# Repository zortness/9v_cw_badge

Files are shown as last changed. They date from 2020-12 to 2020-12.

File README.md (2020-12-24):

# 9V QRP BADGE Transciever

Based on the schematic and work of Jeff Anderson, [K6JCA](https://www.qrz.com/db/k6jca)
and [this blog post](http://k6jca.blogspot.com/2009/08/9v-qrp-transceiver.html).

Variant of the smaller [9V battery-sized version](https://github.com/zortness/9v_cw_tx).

## About

This is a very simple, direct conversion CW transciever that will operate on the 40m 
amateur radio band. It requires an external speaker or headphones, an external antenna,
and a power source between 5 and 12 volts.

**This is still a work in progress.**

Changes from the micro version:
* larger credit card or badge size (55mm X 85mm)
* includes 7-element low pass filter (LPF) based on the QCX design with T-37-2 toroids
* includes ATTiny402 to control keying output, and reading buttons
* includes buttons for DIT and DAH 
* includes 9x2 header pinout for exposing and adding functionality (or fancy covering)

## Schematics

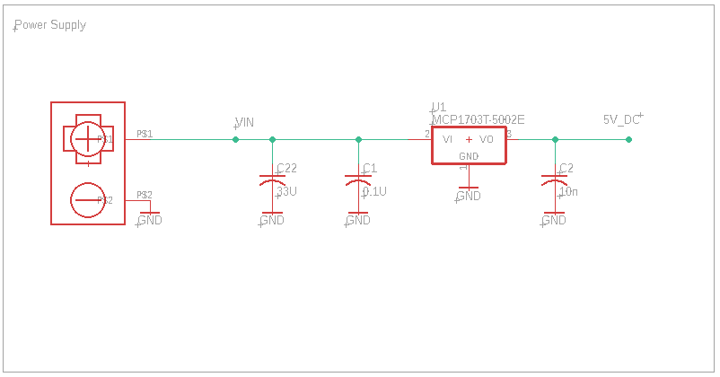
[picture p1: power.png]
Power schematic


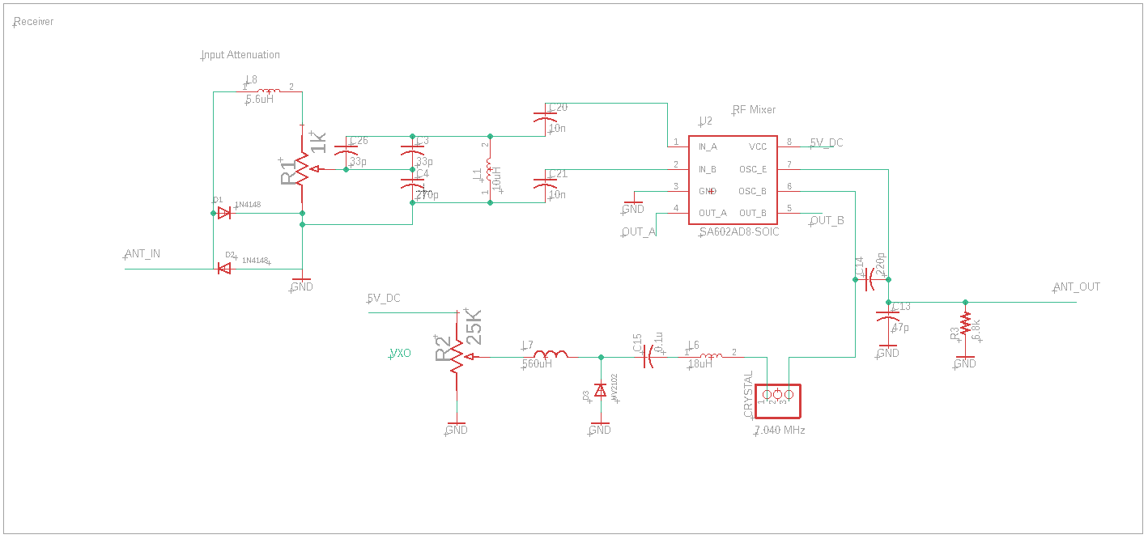
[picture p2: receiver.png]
Receiver schematic


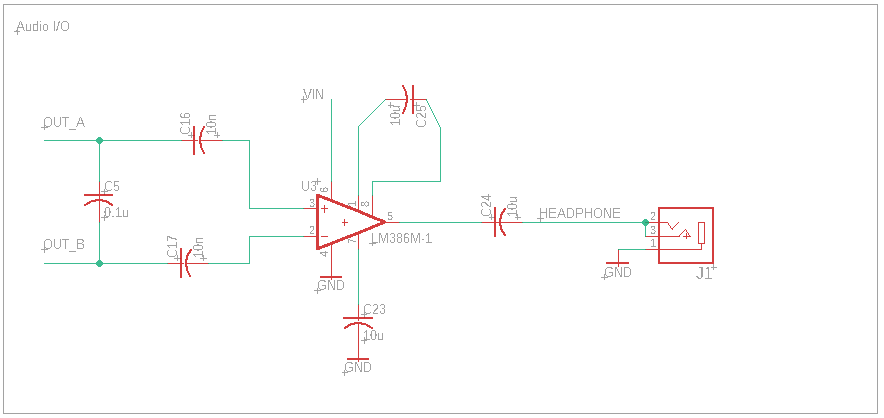
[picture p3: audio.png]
Audio schematic


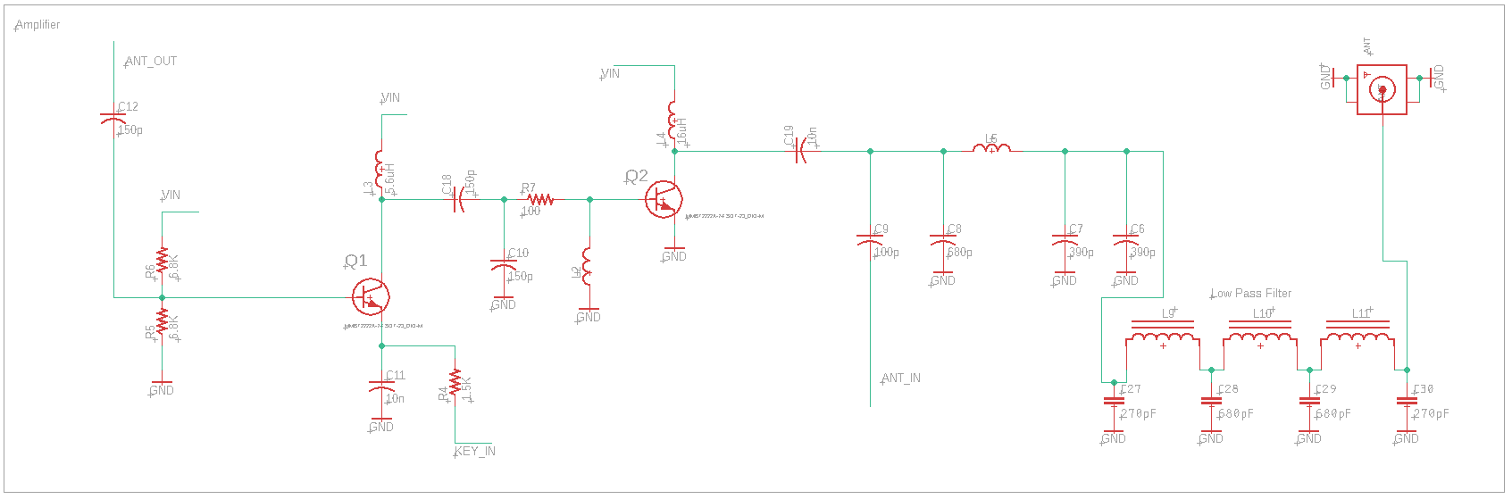
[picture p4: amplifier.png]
Amplifier schematic


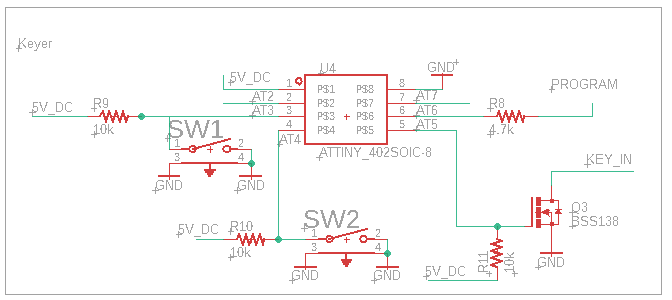
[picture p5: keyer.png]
Keyer schematic


## Board Layouts

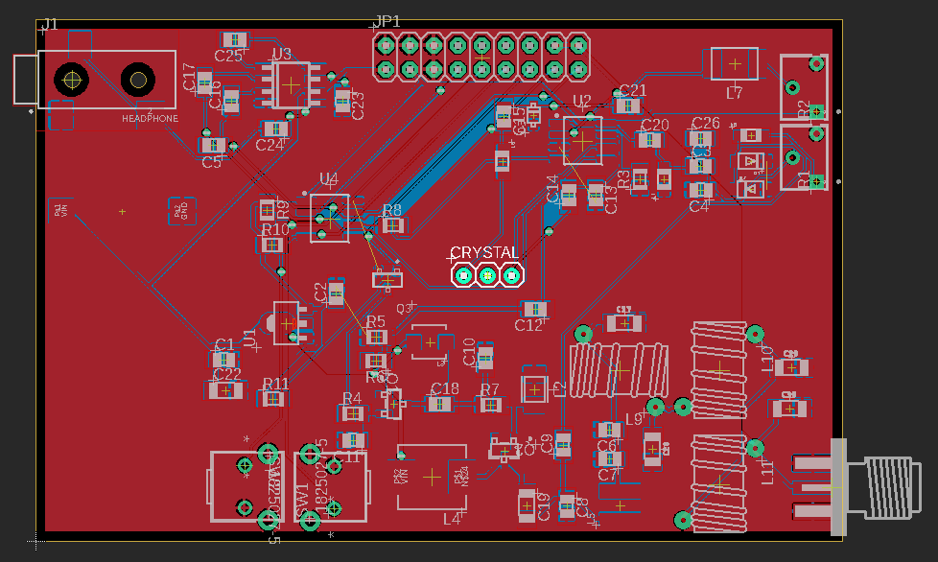
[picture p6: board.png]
Board layout


## SMD BOM

** WIP **

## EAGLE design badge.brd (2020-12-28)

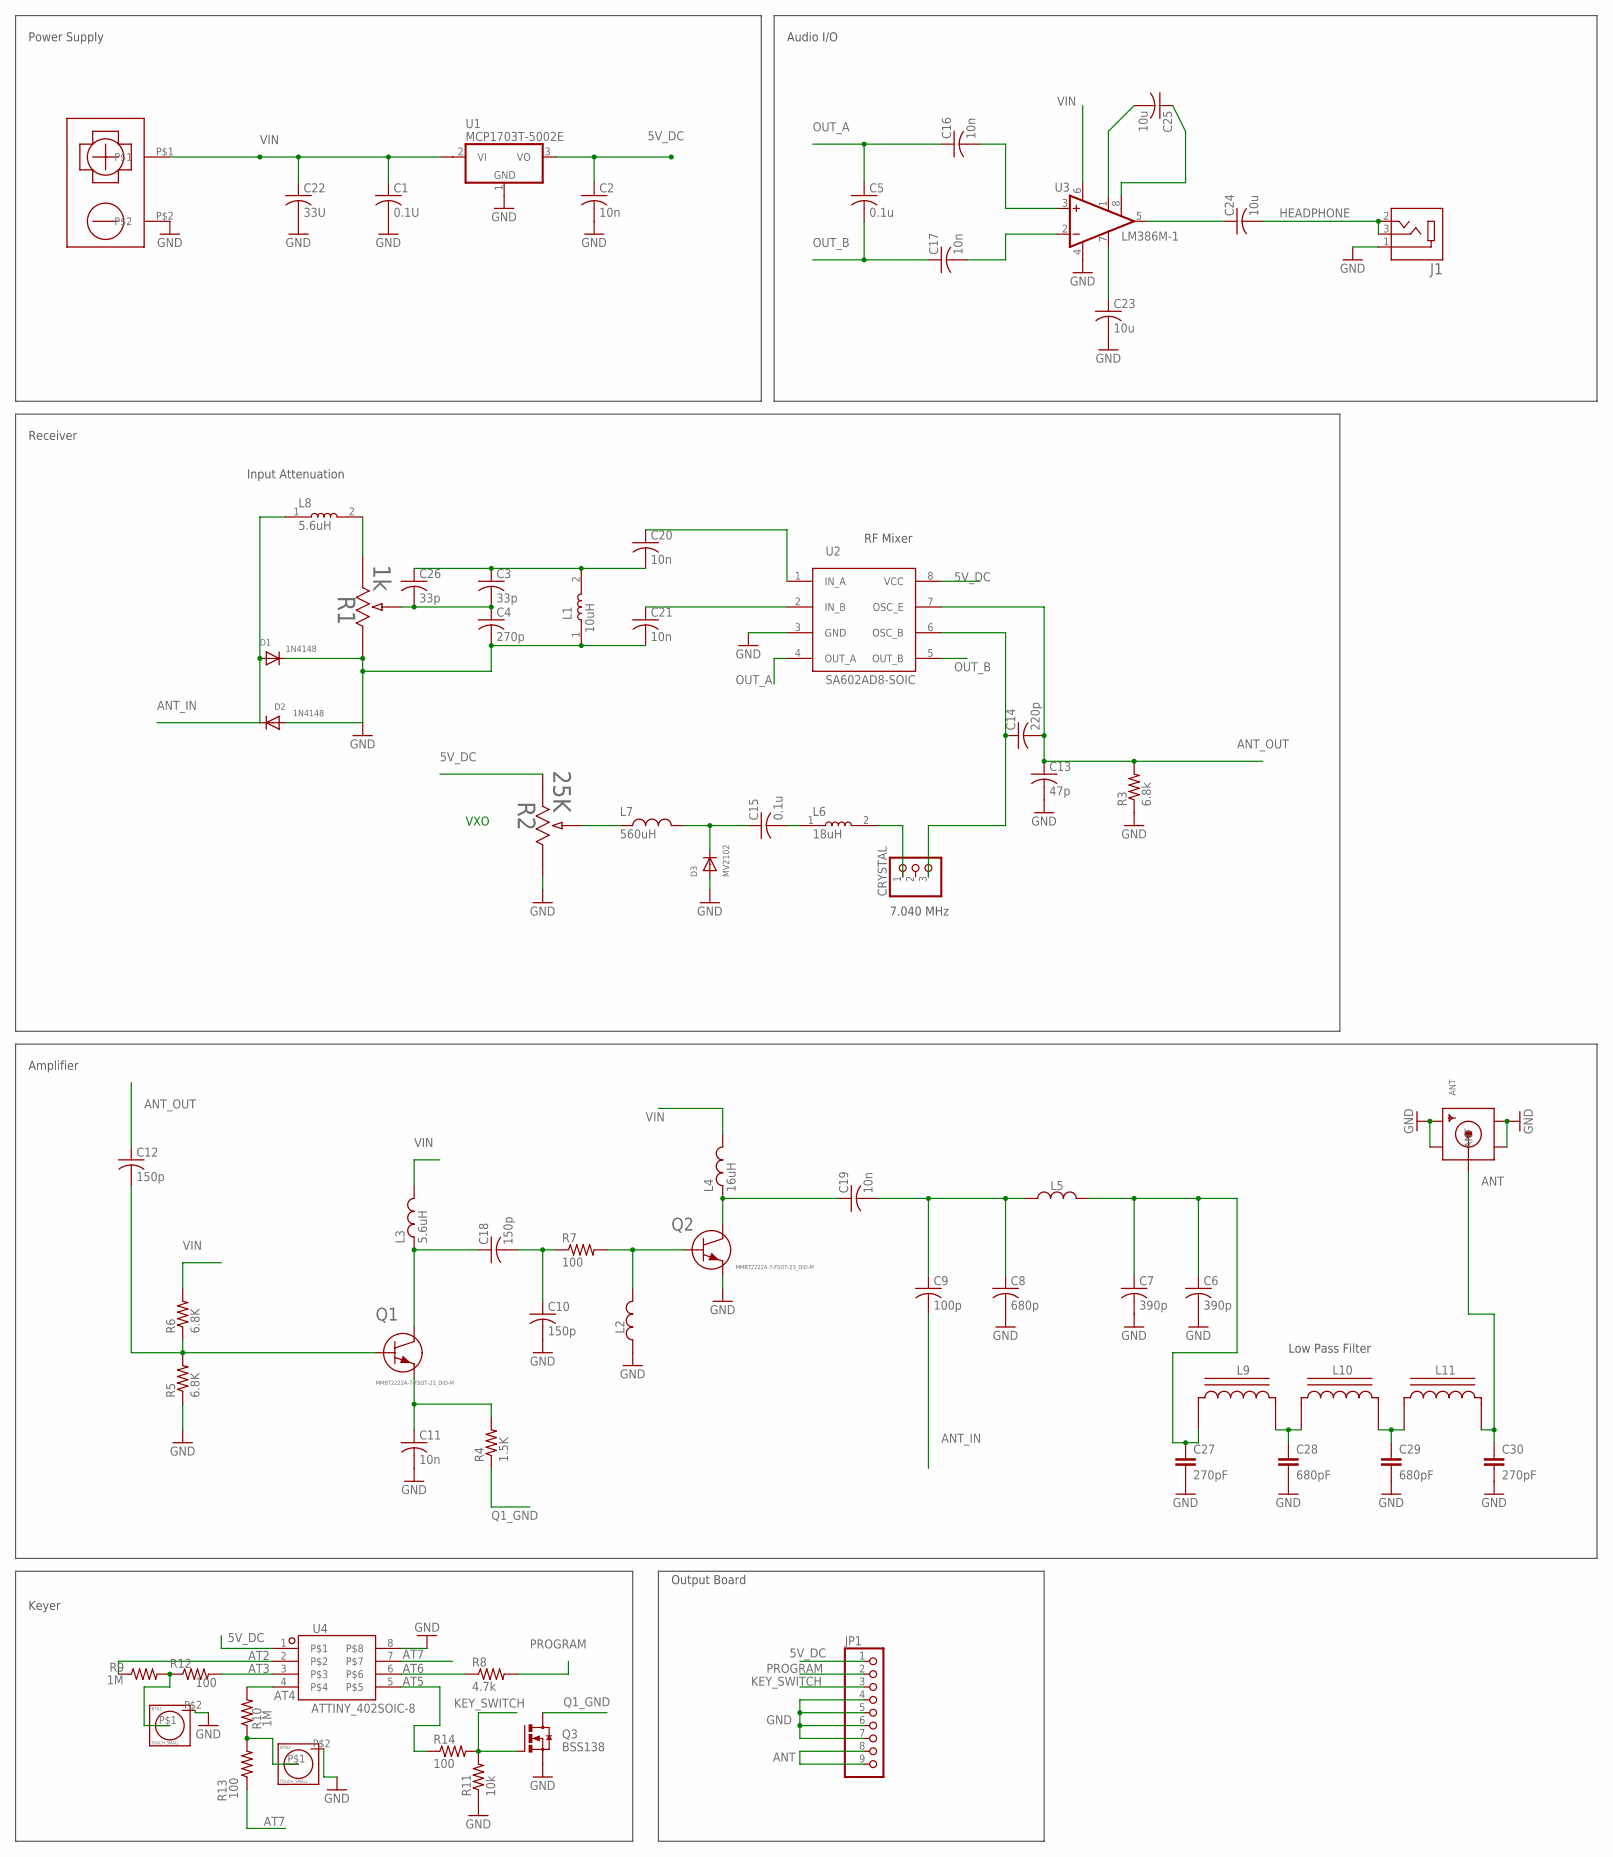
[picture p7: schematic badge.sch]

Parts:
ANT: SMACONNECTOR_EDGE; SMA_EDGELAUNCH
BTN1, BTN2: TOUCH_SMALL
C1: 0.1U; C0805
C2, C11, C16, C17, C20, C21: 10n; C0805
C3, C26: 33p; C0805
C4: 270p; C0805
C5, C15: 0.1u; C0805
C6, C7: 390p; C0805
C8: 680p; C0805
C9: 100p; C0805
C10, C12, C18: 150p; C0805
C13: 47p; C0805
C14: 220p; C0805
C19: 10n; C1206
C22: 33U; C1206
C23, C24, C25: 10u; C0805
C27, C30: 270pF; 1206
C28, C29: 680pF; 1206
CRYSTAL: PINHD-1X3; 1X03
D1, D2: 1N4148; SOD-123FL
D3: MV2102; SOD-323F
J1: SJ-3523-SMT-TR; CUI_SJ-3523-SMT-TR
JP1: PINHD-1X9; 1X09-BIG
L1: 10uH; INDC2012X87N
L2: L_CHIP-1008(2520-METRIC); INDC2520X120N
L3: 5.6uH; SRP3012C
L4: 16uH; ASPI-0630LR
L5: 1.2uH; SRN4018TA
L6: 18uH; INDC2012X87N
L7: 560uH; INDM4532X32_W
L8: 5.6uH; INDC2012X87N
L9, L11: 1.38uH; T37_INDUCTOR
L10: 1.67uH; T37_INDUCTOR
Q1, Q2: MMBT2222A-7-FSOT-23_DIO-M; SOT-23_DIO-M
Q3: BSS138; SOT23-3
R1: 1k; POT_3362W
R2: 25K; POT_3362W
R3: 6.8k; M0805
R4: 1.5K; M0805
R5, R6: 6.8K; M0805
R7, R12, R13, R14: 100; M0805
R8: 4.7k; M0805
R9, R10: 1M; M0805
R11: 10k; M0805
U1: MCP1703T-5002E; SOT89
U2: SA602AD8-SOIC; SOIC127P599X175-8N
U3: LM386M-1; SO08
U4: ATTINY_402SOIC-8; SOIC127P599X175-8N
U$1: 9V_9689V_968_SMD; 9V_968_PAD

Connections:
5V_DC: C2.1, JP1.1, R2.1, U1.3 (VO), U2.8 (VCC), U4.1
ANT: ANT.P (ANT), C30.1, JP1.8, JP1.9, L11.CA
ANT_IN: C9.2, D1.A, D2.C, L8.1
ANT_OUT: C12.1, C13.1, C14.2, R3.2, U2.7 (OSC_E)
AT2: R9.1, U4.2
AT3: R12.2, U4.3
AT4: R10.2, U4.4
AT5: R14.1, U4.5
AT6: R8.1, U4.6
AT7: R13.1, U4.7
GND: ANT.GND@1 (GND4), ANT.GND@3 (GND2), BTN1.P$2, BTN2.P$2, C1.2, C2.2, C4.2, C6.2, C7.2, C8.2, C10.2, C11.2, C13.2, C21.2, C22.2, C23.2, C27.2, C28.2, C29.2, C30.2, D1.C, D2.A, D3.A, J1.1, JP1.4, JP1.5, JP1.6, JP1.7, L1.1, L2.1, Q3.2 (S), R1.3, R2.3, R3.1, R5.1, R11.1, U1.1 (GND), U2.3 (GND), U3.4 (GND), U4.8, U$1.P$2
HEADPHONE: C24.2, J1.2, J1.3
KEY_SWITCH: JP1.3, Q3.1 (G), R11.2, R14.2
unnamed: C20.1, U2.1 (IN_A)
unnamed: C21.1, U2.2 (IN_B)
unnamed: C3.1, C20.2, C26.1, L1.2
unnamed: C3.2, C4.1, C26.2, R1.2
unnamed: L8.2, R1.1
unnamed: C14.1, CRYSTAL.3, U2.6 (OSC_B)
unnamed: C16.2, U3.3 (+IN)
unnamed: C17.2, U3.2 (-IN)
unnamed: C23.1, U3.7 (BYPASS)
unnamed: C25.1, U3.8 (GAIN)
unnamed: C25.2, U3.1 (GAIN)
unnamed: C24.1, U3.5 (OUT)
unnamed: CRYSTAL.1, L6.2
unnamed: C15.2, L6.1
unnamed: C15.1, D3.C, L7.2
unnamed: L7.1, R2.2
unnamed: C12.2, Q1.1, R5.2, R6.1
unnamed: C11.1, Q1.2 (3), R4.2
unnamed: C18.1, L3.P$1 (1), Q1.3 (2)
unnamed: C10.1, C18.2, R7.1
unnamed: L2.2, Q2.1, R7.2
unnamed: C19.1, L4.P$1 (1), Q2.3 (2)
unnamed: C8.1, C9.1, C19.2, L5.P$1 (1)
unnamed: C6.1, C7.1, C27.1, L5.P$2 (2), L9.CB
unnamed: BTN1.P$1, R9.2, R12.1
unnamed: C28.1, L9.CA, L10.CB
unnamed: C29.1, L10.CA, L11.CB
unnamed: BTN2.P$1, R10.1, R13.2
OUT_A: C5.1, C16.1, U2.4 (OUT_A)
OUT_B: C5.2, C17.1, U2.5 (OUT_B)
PROGRAM: JP1.2, R8.2
Q1_GND: Q3.3 (D), R4.1
VIN: C1.1, C22.1, L3.P$2 (2), L4.P$2 (2), R6.2, U1.2@1 (VI1), U3.6 (VS), U$1.P$1

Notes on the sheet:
Power Supply
Audio I/O
Input Attenuation
RF Mixer
VXO
7.040 MHz
Receiver
Amplifier
Low Pass Filter
Keyer
Output Board

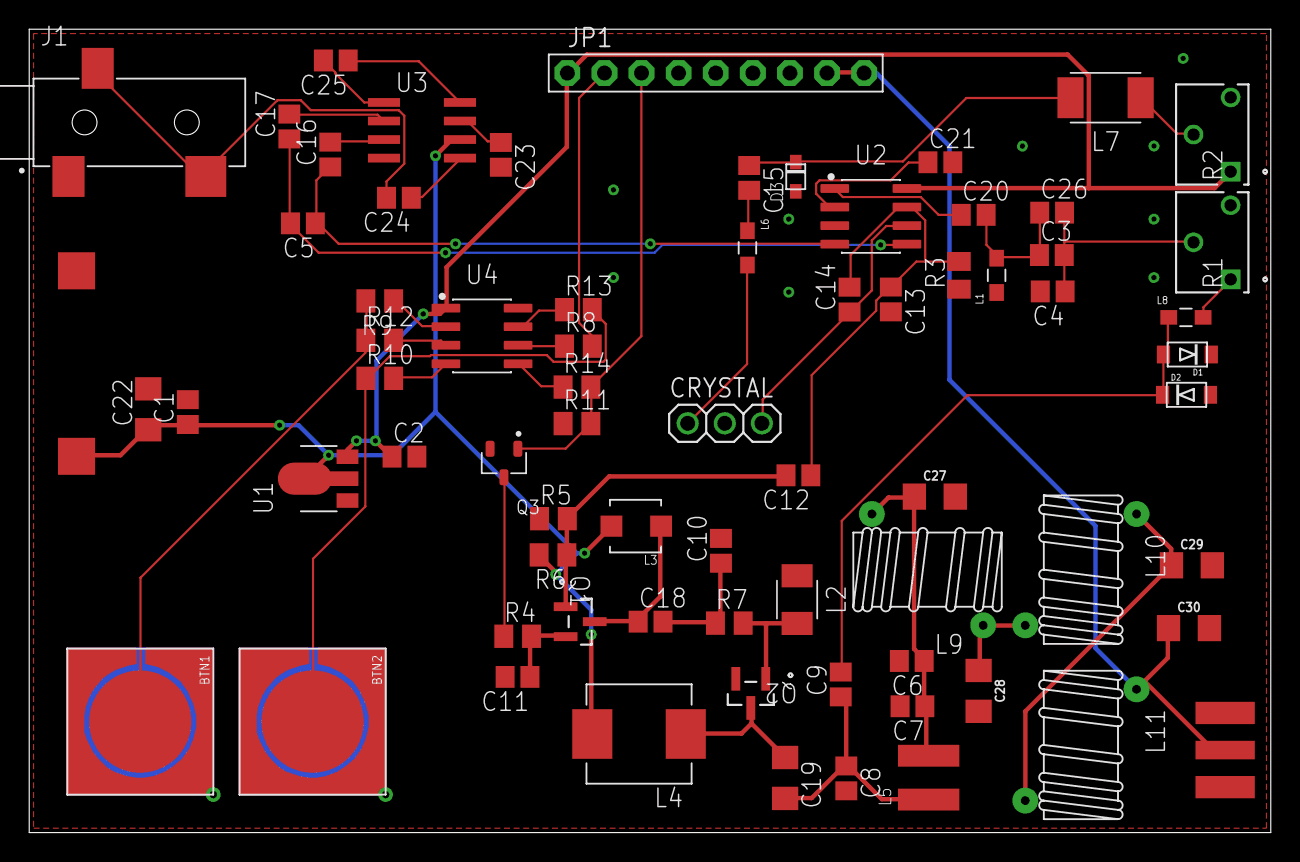
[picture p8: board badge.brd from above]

Board: 2 copper layers, 85.0 x 55.0 mm, 72 parts (0 on the bottom side), 46 nets.

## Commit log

2020-12-23 initial commit
    * clone of the 9V TX
    * added a low pass filter on the output
    Still to do
    * ATTiny keyer
    * buttons
    [badge.brd, badge.sch]
2020-12-24 updates
    * added ATTiny keyer and buttons
    * added breakout jumper
    * added images
    * added README
    [badge.brd, badge.sch]
2020-12-28 moving to capacitive touch
    Not ready for production
    * replaced switches with capacitive touch buttons
    * slight cleanup pass
    [badge.brd, badge.sch]

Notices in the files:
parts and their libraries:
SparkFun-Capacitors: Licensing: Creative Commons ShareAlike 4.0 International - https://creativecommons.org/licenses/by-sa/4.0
